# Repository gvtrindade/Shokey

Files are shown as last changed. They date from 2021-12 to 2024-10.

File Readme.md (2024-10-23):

# Shokey icon Shokey 




An Arduino based Shortcut Keypad and Python app.

<p align="center">
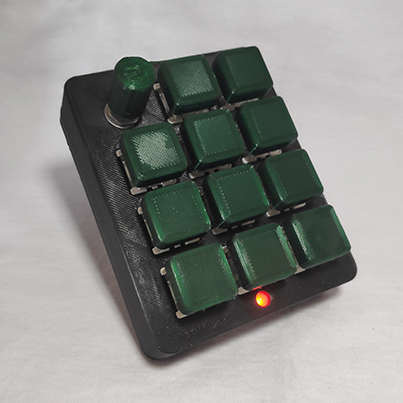
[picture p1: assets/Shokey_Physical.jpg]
Shokey layout in numeric keypad mode
  
</p>

<br>

<details>
<summary>Table of Contents</summary>

  - [Arduino](#-arduino)
    - [Features](#features)
    - [Usage](#usage)
    - [Bill of Materials](#materials)
    - [Assembling the Hardware](#hardware)
    - [Flashing the Software](#firmware)
  - [Python](#-python)
    - [Features](#features-1)
    - [Installation](#installation)
    - [Usage](#usage-1)
    - [Shokey Layout](#layout)
    - [Shortcut Editing](#shortcuts)
    - [Custom Keys](#custom-keys)
  - [References](#-references)
</details>

## ♾ Arduino

The hardware was made using an Arduino Pro Micro, Cherry MX Brown Switches, and 3D printed shell and keycaps.

### Features
- Can be used as a numeric keyboard while not running the app
- Has a cool RGB LED that changes color!

### Usage
To use your Shokey as a numeric keypad, just connect it to your device (PC, Linux, Mac or Android) and start pressing the keys.
<p align="center">
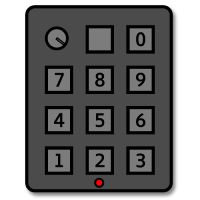
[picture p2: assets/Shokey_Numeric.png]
Shokey layout in numeric keypad mode
  
</p>

<details>
<summary>
    🛒
    <span id="materials" style="font-size: 1.3em; font-weight: 500">Bill of materials</span>
</summary>
<br>

- Arduino Pro Micro
- 11 Cherry MX like switches
- 11 Single way diodes
- Rotary Encoder
- RGB LED

<hr style="height: 0.1rem">

</details>

<details>
<summary>
    ⚙
    <span id="hardware" style="font-size: 1.3em; font-weight: 500">Assembling the hardware</span>
</summary>

1. [Download](https://thangs.com/designer/gabrielsvtrindade/3d-model/Shokey-199656) and print the shell, keycaps and rotary encoder knob

2. Place all switches and screw in the rotary encoder to the top part of the shell

3. Solder the switches, rotary encoder and RGB LED to their respective pins in the Arduino, following the [wiring diagram](./assets/Wiring_Diagram.png)

4. Close the shell, screw it and glue the rubber feet

<hr style="height: 0.1rem">

</details>

<details>
<summary>
    ⚡️
    <span id="firmware" style="font-size: 1.3em; font-weight: 500">Flashing the firmware</span>
</summary>

1. Make sure you have <a target="_blank" href="https://www.arduino.cc/en/software">Arduino IDE</a> installed

2. Go to "Sketch > Include Library > Manage Libraries"

<p align="center">
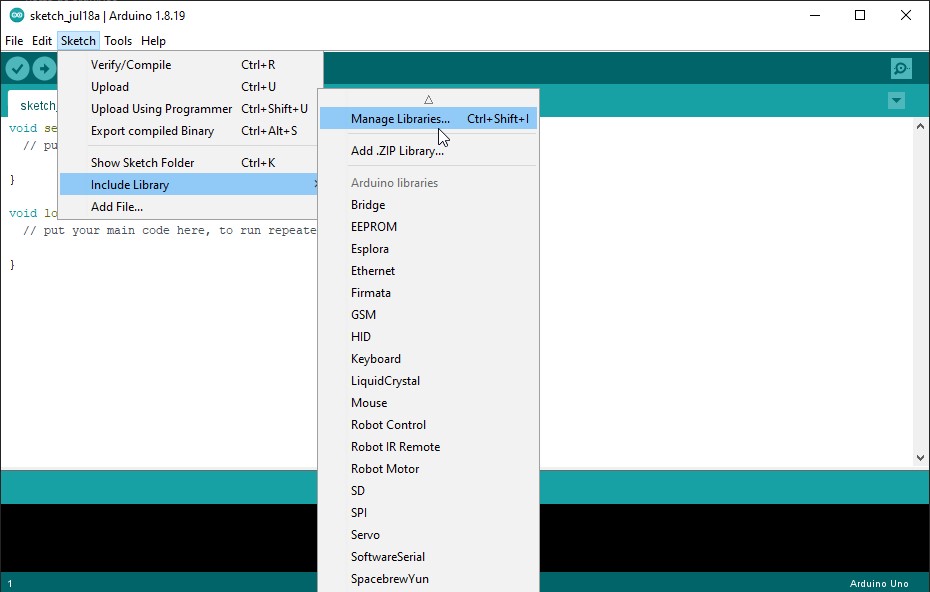
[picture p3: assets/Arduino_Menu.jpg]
Arduino library installation
  
</p>

3. Search for and install the Bounce2, Encoder, Keyboard and Keypad libraries

<p align="center">
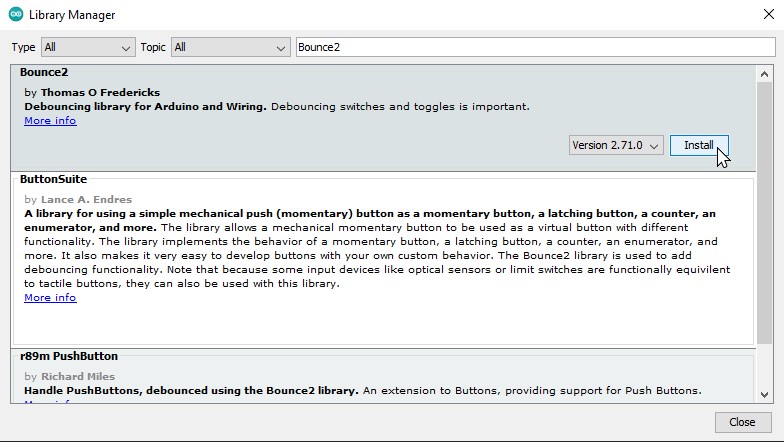
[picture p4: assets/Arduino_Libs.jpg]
Arduino library installation
  
</p>

4. [Download](https://github.com/gvtrindade/Shokey/releases) and unzip the **Firmware.zip** file

5. Copy the "hardware" folder to your "Documents/Arduino" folder

6. Go to the "File > Open" folder and navigate to "Firmware/Shokey/Shokey.ino"

7. Go to "Tools > Board > gvtrindade-avr" and select "Arduino Leonardo Shokey"

<p align="center">
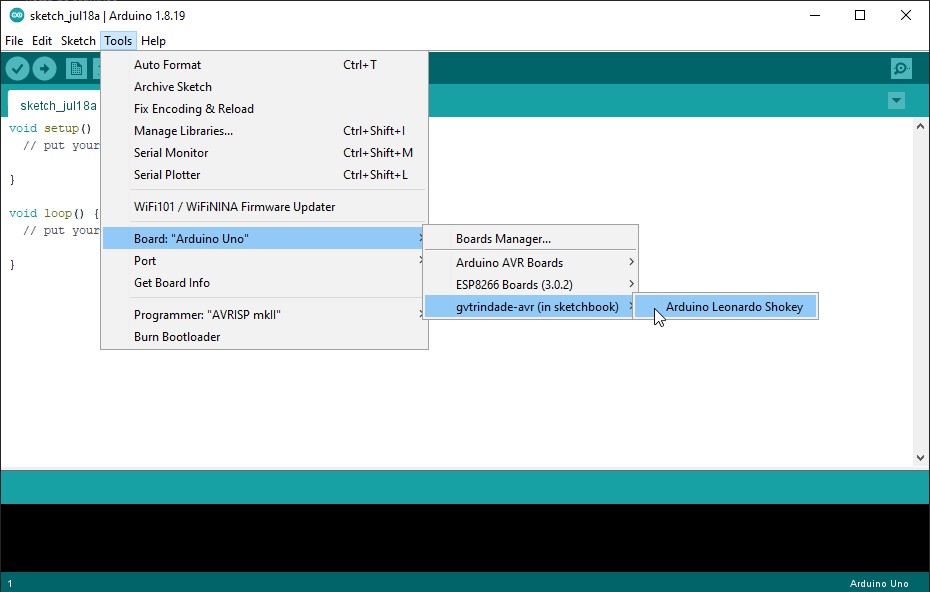
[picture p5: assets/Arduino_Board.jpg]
Arduino library installation
  
</p>

8. Go to "Tools > Ports" and take note of the ports shown

9. Connect your Shokey, reopen "Tools > Ports" and select the COM port that just appeared

<p align="center">
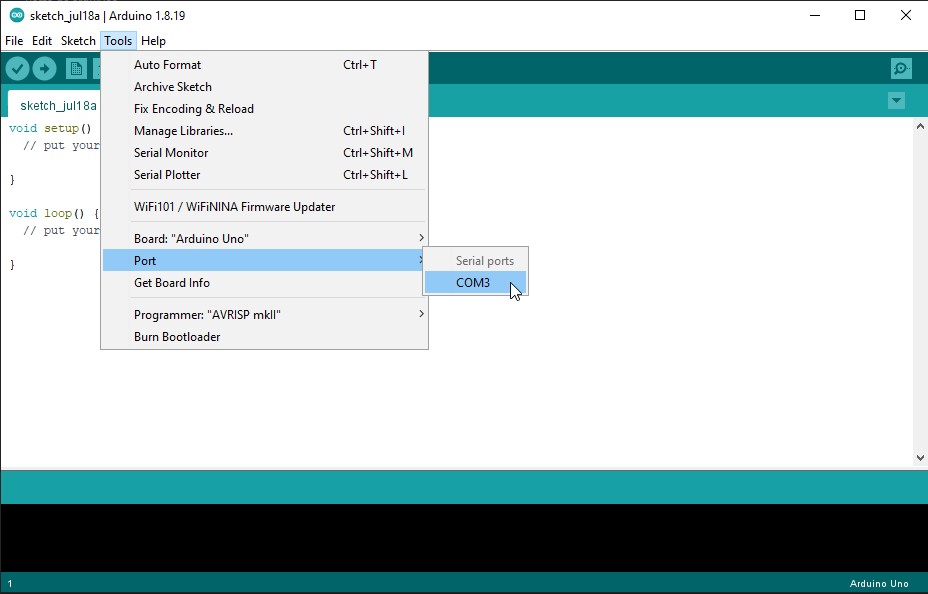
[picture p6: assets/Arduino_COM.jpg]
Arduino library installation
  
</p>

10. Go to "Sketch > Upload"

When the upload is complete, you can already use your Shokey as numeric keypad, but if you want to have the full shortcut experience, you'll have to [install the application](#installation)

<hr style="height: 0.1rem">

</details>

<br>

## 🐍 Python

The app connects to a Shokey and is used for sending and editing the shortcuts

<p align="center">
  Right clicked task bar icon
</p>

### Features

- Maps keystrokes, key combinations, writes text, opens programs and scroll pages
- Detects automatically whether a Shokey is connected to the PC
- Cute thunderstorm icon

### Installation

1. [Download](https://github.com/gvtrindade/Shokey/releases) and unzip the **Application.zip** file

2. Connect your Shokey

3. Open "Application/Shokey.exe"

### Usage

- While the app is open, there will be a cute thunderstorm icon near our PCs clock
- Double clicking it will open the "shortcuts.txt" file, allowing you to [edit your shortcuts](#shortcut-editing)
- Right clicking it will open a menu to open the Shortcuts file, About file or quit the app:

<p align="center">
  Right clicked task bar icon
</p>

<details>
<summary>
    🧮
    <span id="layout" style="font-size: 1.3em; font-weight: 500">Shokey Layout</span>
</summary>
<br>

Shokey has 4 layers (red, green, blue and white) and the `*` key is used to change between layers

<p align="center">
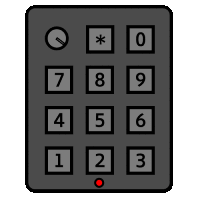
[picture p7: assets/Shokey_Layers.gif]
Cycling through Shokeys layers
  
</p>

<br>

The rotary encoder is represented by three variables, `VU` (Volume Up), `VD` (Volume Down) and `E` (Encoder button)

<p align="center">
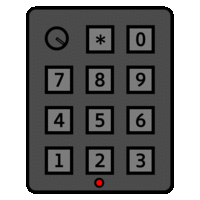
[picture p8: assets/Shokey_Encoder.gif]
Encoder rotating and clicking function
  
</p>

<hr style="height: 0.1rem">

</details>

<details>
<summary> 
    📝
    <span id="shortcuts" style="font-size: 1.3em; font-weight: 500">Shortcut Editing</span> 
</summary>
<br>

In the "shortcuts.txt" is where all the magic happens, here is where you write the shortcuts that will be played when you press a key in your Shokey.

The file has 4 sets of lines, 1 for each color.

- To add a shortcut, you'll have to find the key that you want to press, based on the [layout](#shokey_layout), as well as the color and add the shortcut after the `;`.
- After writing the desired shortcut, *save* the file and close it.
- The change will only take effect after the second time the button is pressed.
- Shortcuts will only work if the corretct syntax is used

There are examples of shortcuts in the file, but you can use this list to help you write your own:

- Key shortcut: `key.*key*`
- Combo of keys shortcut: `combo.*key1*+*key2*`
- Write text shortcut: `txt.*text*`
- Open a program shortcut: `link.*full_exe_adress*`
- Scroll the page shortcut: `scroll.*horizontal value*, *vertical Value*`

##### 
    1R; key.a
    2G; combo.alt+f4
    3B; txt.Hello World
    4W; link.C:\Windows\System32\calc.exe
    ER; key.media_play_pause
    VUG; scroll.0,-1
    VDG; scroll.0,1

<hr style="height: 0.1rem">

</details>

<details>
<summary> 
    🏷
    <span id="custom-keys" style="font-size: 1.3em; font-weight: 500">Custom Keys</span> 
</summary>
<br>

Some keys are special, the following list has some examples:
#####
    key.media_play_pause    //play and pause control
    key.media_volume_up     //volume up
    key.media_volume_down   //volume down
    combo.ctrl+c            //copy selection

There's a variety of keys
- f2, f5, space, escape, delete, home, end
- ctrl, alt, shift, cmd (windows key)
- up, down, left, right
- <a target="_blank" href="https://pynput.readthedocs.io/en/latest/keyboard.html#pynput.keyboard.Key">More key codes</a>

<hr style="height: 0.1rem">

</details>

## 🔎 References
 
- [Programmable Macropad v2 - 
Tiny Boat Productions](https://www.instructables.com/Programmable-Macropad-V2/)
- [MIDI device name - musinou](http://liveelectronics.musinou.net/MIDIdeviceName.php)
- [Bounce2](https://www.arduino.cc/reference/en/libraries/bounce2/), [Encoder](https://www.arduino.cc/reference/en/libraries/encoder/), [Keyboard](https://www.arduino.cc/reference/en/libraries/keyboard/), [Keypad](https://www.arduino.cc/reference/en/libraries/keypad/)
- [Pynput](https://pypi.org/project/pynput/), [Pyserial](https://pypi.org/project/pyserial/), [Systray](https://github.com/Infinidat/infi.systray)
- Icons made by Freepik from flaticon.com

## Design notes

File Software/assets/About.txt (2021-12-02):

Shokey

An Arduino based Shortcut Keypad and Python app.

Created by: github.com/gvtrindade/Shokey
Version: v1.0
Date: 12/02/2021

Python: v3.9
Libs:
  pynput
  pyserial
  SysTrayIcon

Arduino: v1.8.15
Libs:
  Bounce2
  Encoder
  Keyboard
  Keypad

Icons made by Freepik from flaticon.com

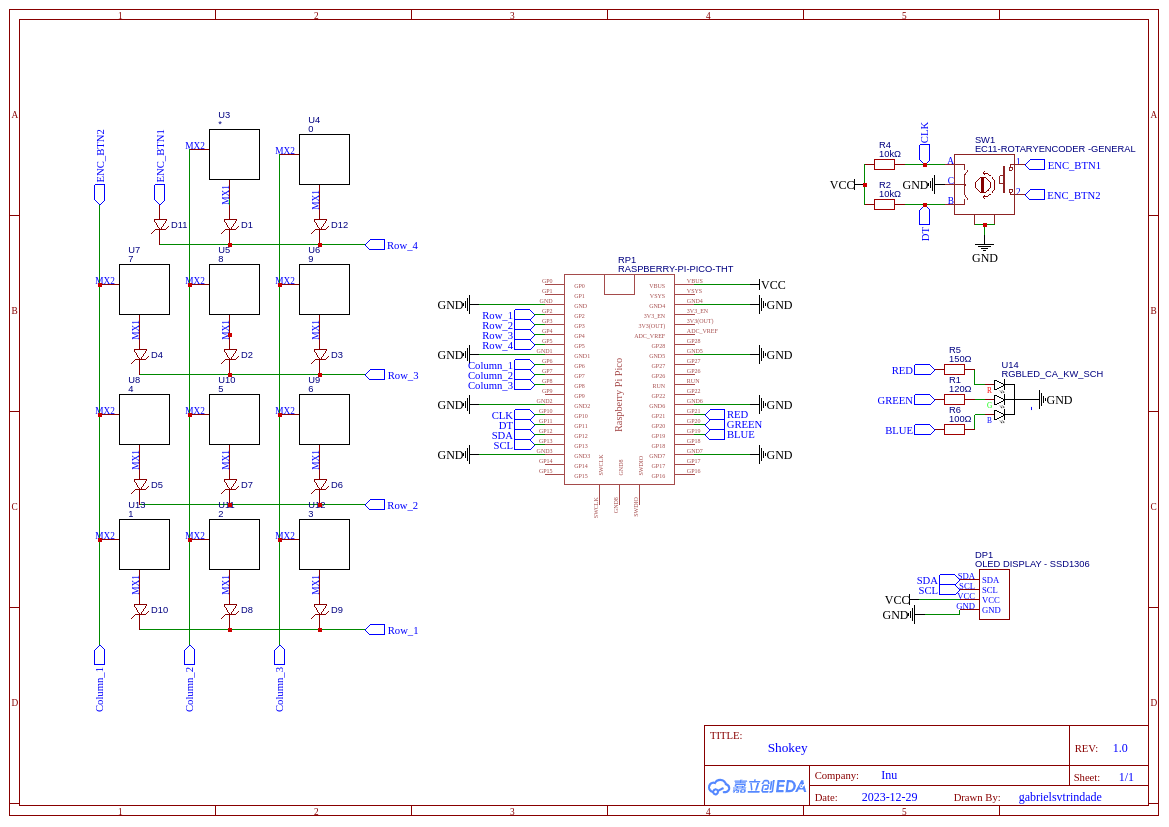
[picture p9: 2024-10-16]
Hardware/v2/Schematic.png

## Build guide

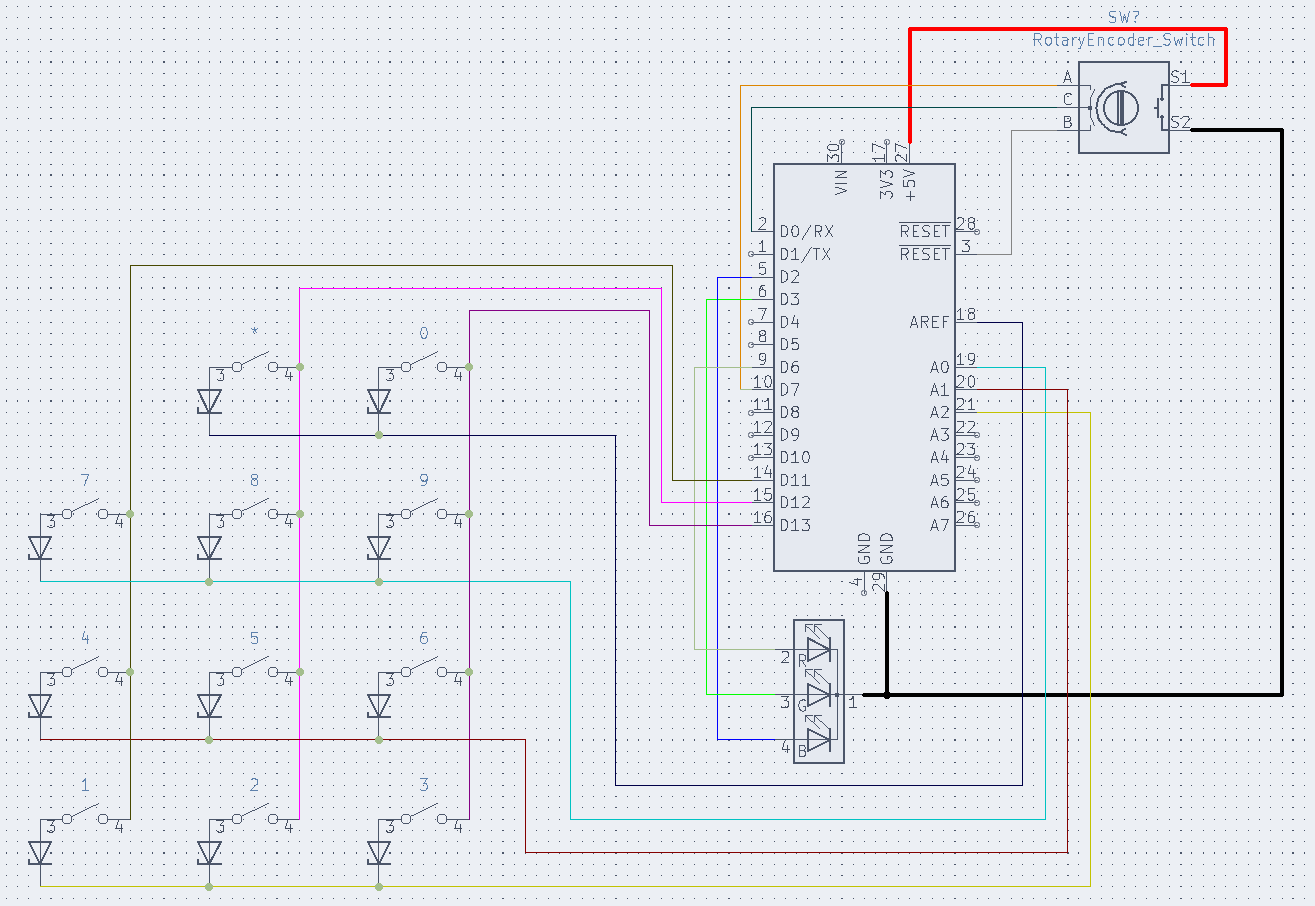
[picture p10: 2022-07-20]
assets/Wiring_Diagram.png

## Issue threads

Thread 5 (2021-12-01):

Write an extensive readme

gvtrindade, 2021-12-01:
- [x] Arduino wiring diagram
- [x] Arduino software installation
- [x] Custom board name installation
- [x] Python software instructions

gvtrindade, 2021-12-01:
Document the steps to assembling a shokey, installing the software to the arduino, including the custom name and installing and running the python application

gvtrindade, 2022-07-20:
Done

Closed 2022-07-20.

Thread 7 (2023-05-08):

Refactor board validation in the desktop app

gvtrindade, 2023-05-08:
- Change both arduino and pico's usb comment to 'Shokey'
- Refactor app to look for comment instead of PID and UID

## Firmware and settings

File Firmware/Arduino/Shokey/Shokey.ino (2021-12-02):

/**
 * @file Shokey.ino
 * @author Gabriel Trindade (github.com/gvtrindade)
 * @brief This is the arduino part of the code, 
 * here the button inputs are captured and sent via serial
 * communication to the python part of the code.
 * @version 1.0
 * @date 2021-07-05 
 * 
*/

//Include the libraries that will be used
#include <Keypad.h>
#include <Encoder.h>
#include <Bounce2.h>
#include <Keyboard.h>

//State keys matrix, pins and setup keypad
const byte ROWS = 4;
const byte COLS = 3;
char keys[COLS][ROWS] = {
    {'X', '7', '4', '1'},
    {'*', '8', '5', '2'},
    {'0', '9', '6', '3'}};
byte rowPins[ROWS] = {18, 19, 20, 21};
byte colPins[COLS] = {15, 14, 16};
Keypad keypad = Keypad(makeKeymap(keys), colPins, rowPins, COLS, ROWS);

//Set led pins, led brightness and current selected color
const int redL = 9;
const int greenL = 6;
const int blueL = 5;
const int brightness = 5;
char currColor;

//Set encoder pins, setup encoder and its button, the debounce interval,
// encoder's old position rotation time limit and delay
int SW = 10;
int DT = 2;
int CLK = 3;
Encoder volumeKnob(DT, CLK);
Bounce2::Button encoderButton = Bounce2::Button();
const int debounceInterval = 5;
long oldPosition = -999;
const int rotationDelay = 80;

//Define character to be recieved from the macro script
//and whether or not it's running
char incomingString;
bool scriptRunning = false;

//Function to change shown led color: red, green, blue or white
void changeColor()
{

  switch (currColor)
  {
  case 'W':
    analogWrite(redL, brightness);
    analogWrite(greenL, 0);
    analogWrite(blueL, 0);
    currColor = 'R';
    break;

  case 'R':
    analogWrite(redL, 0);
    analogWrite(greenL, brightness);
    analogWrite(blueL, 0);
    currColor = 'G';
    break;

  case 'G':
    analogWrite(redL, 0);
    analogWrite(greenL, 0);
    analogWrite(blueL, brightness);
    currColor = 'B';
    break;

  case 'B':
    analogWrite(redL, brightness);
    analogWrite(greenL, brightness);
    analogWrite(blueL, brightness);
    currColor = 'W';
    break;
  }
}

// Test communication between keypad and the macro script,
// if the script is on, it returns true, else, false
void testCommunication()
{
  incomingString = Serial.read();
  switch (incomingString)
  {
  case 'I':
    scriptRunning = true;
    break;
  case 'O':
    scriptRunning = false;
    break;
  }
}

void normalKeyPressing(char pressedKey)
{
  //Press key based on assigned key on "keys" matrix
  if (pressedKey != NO_KEY)
  {
    switch (pressedKey)
    {
    case '*':
      changeColor();
      break;
    default:
        Keyboard.press(pressedKey);
        Keyboard.release(pressedKey);
      break;
    }
  }
}

void programKeyPressing(char pressedKey)
{
  //Check if a key is pressed, sending its value to the serial port
  //Depending on the current led color, a different value will be sent,
  //effectively creating a profile for each color.
  //eg. '1R' = number 1 in the red profile
  String keyCode = String(pressedKey) + String(currColor);
  if (pressedKey != NO_KEY)
  {
    switch (pressedKey)
    {
    case '*':
      changeColor();
      break;
    default:
      Serial.println(keyCode);
      break;
    }
  }
}

void encoderButtonPressing()
{
  // Check if the encoder button is pressed, send its value in the same format as the number keys
  if (encoderButton.update() && encoderButton.isPressed())
  {
    String buttonCode = "E" + String(currColor);
    Serial.println(buttonCode);
  }
}

void encoderRotating()
{
  //Check encoder rotation, sending VU when the encoder is rotated clockwise, and VD, when counterclockwise
  long newPosition = volumeKnob.read();
  if (newPosition != oldPosition)
  {
    if ((newPosition - oldPosition) > 0)
    {
      String volumeUpCode = "VU" + String(currColor);
      Serial.println(volumeUpCode);
    }
    else
    {
      String volumeDownCode = "VD" + String(currColor);
      Serial.println(volumeDownCode);
    }
    oldPosition = newPosition;
    delay(rotationDelay);
  }
}

void setup()
{
  //Begin serial communication
  Serial.begin(9600);
  Keyboard.begin();

  //Set led pins, set current color and run changeColor() to set first color as red
  pinMode(redL, OUTPUT);
  pinMode(greenL, OUTPUT);
  pinMode(blueL, OUTPUT);
  currColor = 'W';
  changeColor();

  //Set encoder pins, its pressing interval and pressed state
  pinMode(CLK, INPUT_PULLUP);
  encoderButton.attach(SW, INPUT);
  encoderButton.interval(debounceInterval);
  encoderButton.setPressedState(LOW);
}

void loop()
{
  //Call communication test, key pressing and encoder rotating functions
  testCommunication();
  switch (scriptRunning)
  {
  case true:
    programKeyPressing(keypad.getKey());
    break;
  case false:
    normalKeyPressing(keypad.getKey());
    break;
  }
  encoderButtonPressing();
  encoderRotating();
}

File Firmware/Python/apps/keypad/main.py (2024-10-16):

import usb_hid
from adafruit_hid.keyboard import Keyboard


class KeypadApp:
    def __init__(self, hardware_keys):
        self.keyboard = Keyboard(usb_hid.devices)
        self.hardware_keys = hardware_keys

    def press_key(self, event):
        key = self.hardware_keys[event.key_number]
        if event.pressed:
            self.keyboard.press(key)
        else:
            self.keyboard.release(key)

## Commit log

2021-11-17 Folders organized
    [Base.stl, Keycap.stl, Knob.stl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]
2021-12-05 Readme update/Wiring diagram added
2021-12-06 Readme updated
    [Wiring_Diagram.fzz]
2022-07-20 Reestructure readme file
    [Custo.xlsx]
2024-10-16 feat: add pi pico python version
    [Wiring_Diagram.fzz]
